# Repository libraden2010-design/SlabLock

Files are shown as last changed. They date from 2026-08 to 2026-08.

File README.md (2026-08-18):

# SlabLock

A 3D-printed display case for PSA-graded card slabs, designed in OpenSCAD and printed on a Bambu X2D (PLA).

## Features

- Slide-lock lid with 45-degree dovetail rails (no flex parts, nothing breaks)
- Side magnets (8x2mm N52) for case-to-case linking
- Flat stacking with chamfered rim keying
- Single-piece lid (V5) with retaining groove for clear plastic sheet
- Push-out hole for easy slab removal

## Files

- `POLYGENCE_SLIDE_LOCK.scad` — parametric OpenSCAD source (single file, all parts)
- `BUILD_LOG.md` — design iteration history, mistakes, and lessons learned
- `stl/` — exported STL files by version

## Printing

- **Printer**: Bambu X2D (or any FDM)
- **Material**: PLA
- **Export**: Set `export_part` in the SCAD file — `"frame"` or `"lid"`
- **Orientation**: Frame prints back-face down, lid prints mating-face down
- **No supports needed**

## Clear Sheet

Cut a clear plastic sheet (PET or acetate) to the dimensions shown in the OpenSCAD console output. The sheet slides into the lid's C-channel grooves from the top edge.

## Magnets

8x2mm N52 neodymium discs, 3 per side. Use CA glue or 5-minute epoxy (not Gorilla Glue). Mark polarity with Sharpie before installing.

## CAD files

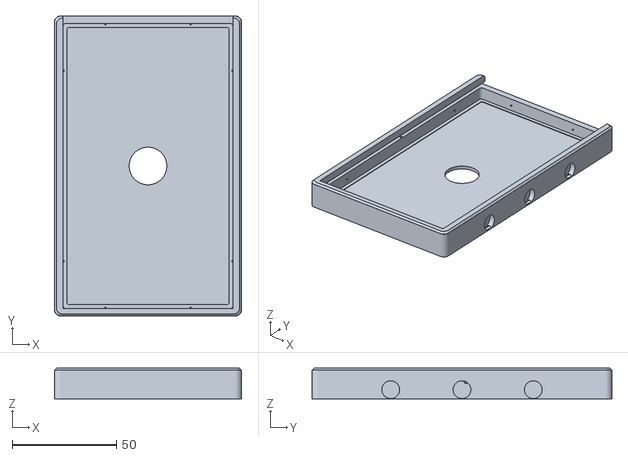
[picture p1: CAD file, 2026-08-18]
stl/v5/Frame.stl
89.6 x 143.6 x 14.7

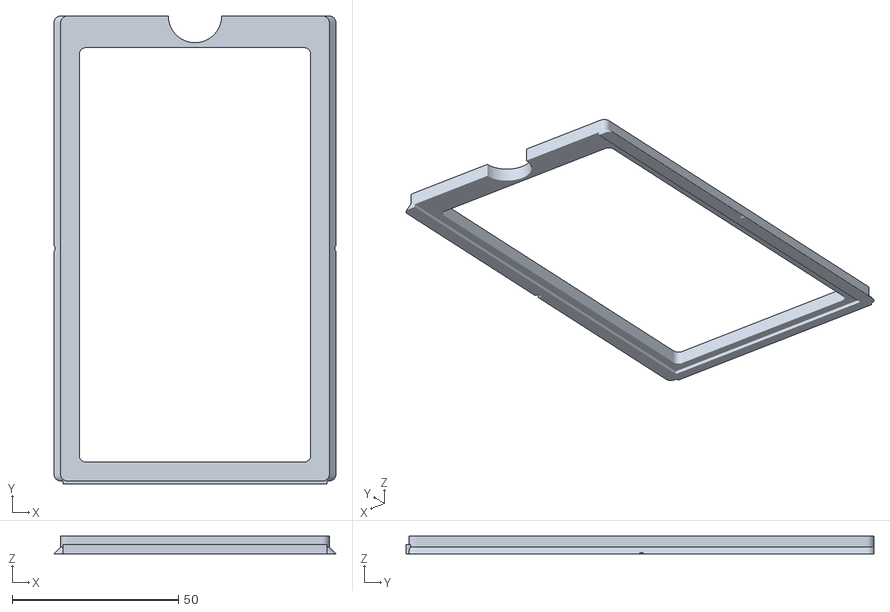
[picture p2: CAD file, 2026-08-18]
stl/v5/Lid-Single-Piece.stl
84.8 x 140.7 x 5.30

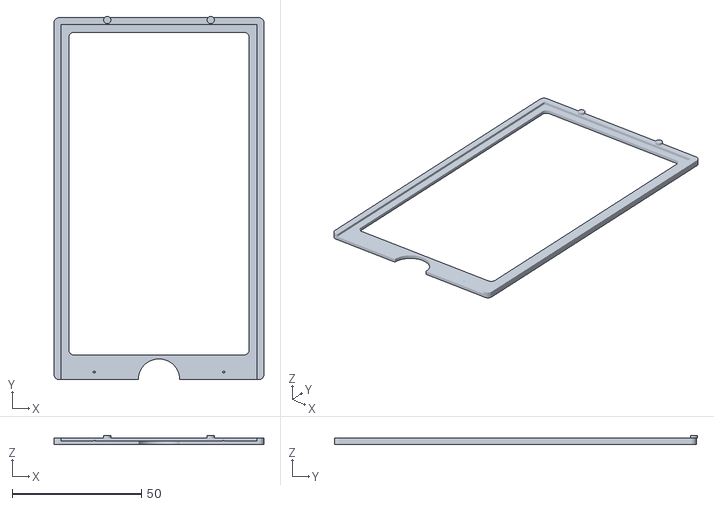
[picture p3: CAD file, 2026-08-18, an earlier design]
stl/v4/Lid-Front-V4.stl
81.1 x 140.3 x 3.50

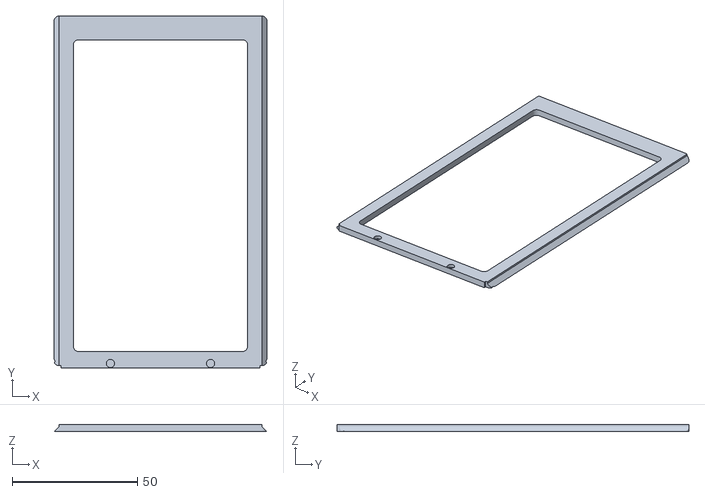
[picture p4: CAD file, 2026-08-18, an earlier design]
stl/v4/Lid-Back-V4.stl
85.1 x 140.7 x 2.80

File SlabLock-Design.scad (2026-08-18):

// ============================================================
// PSA Slab Display — V5: SINGLE-PIECE LID
// ============================================================
// The lid SLIDES into the frame from the top edge, like a
// battery cover:
//   - Frame side walls extend up into dovetail RAILS that wrap
//     over the lid's chamfered edges (captures it vertically)
//   - A raised STOP WALL at the bottom edge ends the travel
//   - A tiny detent bump clicks into a divot in the lid at the
//     seated position
// NOTHING flexes more than a few hundredths of a mm -> nothing
// breaks, in any material.
//
// The lid is ONE PIECE (5.3mm) with a rabbet (shallow recess)
// on the mating face for the clear sheet. No sandwich, no pins,
// no second plate.
//
// PRINT (all flat, no supports):
//   "frame" - rails print with 45-degree self-supporting undersides
//   "lid"   - prints mating-face-DOWN (chamfers slope inward = safe)
//
// CLEAR SHEET: see echo() output for dimensions.
// ============================================================

// ---- EXPORT MODE ----
// "frame" | "lid" | "assembled"
export_part = "assembled";

// ---- Slab + fit ----
slab_w = 81;  slab_h = 136;  slab_t = 6.5;
fit = 0.3;  mag_tol = 0.15;

// ---- Walls ---- (original proportions — the slim pass was reverted)
back_t = 2.0;  wall_t = 4.0;  bot_t = 3.5;  top_t = 3.5;  corner_r = 3;

// ---- Slab pocket rim ----
rim_w = 2.0;  rim_extra = 0.3;

// ---- Side magnets (case-to-case linking; flush mount) ----
// 6x2 (not 6x3): a 2mm-deep seat can sit CENTERED on the tall wall
// without breaking into the dovetail channel behind it.
// Bore is 0.4 oversize so printed-hole shrinkage can't block the
// magnet — the crush ribs (sized off mag_d, not the bore) do the
// actual gripping.
// 8x2: biggest disc that sits CENTERED on the wall — the thin 2mm
// profile keeps the seat shallow enough to clear the lid channel.
mag_d = 8;  mag_t = 2;  mags_per_side = 3;
mag_hole_d = mag_d + 0.5;
mag_seat_depth = mag_t + 1.0;   // 3mm bore — magnet at back, 1mm gap for superglue plug

// ---- Closure magnets (lid <-> frame, optional helpers now) ----
cmag_d = 5;  cmag_t = 2;  cmag_tol = 0.2;
cmag_hole_d = cmag_d + cmag_tol;

// ---- Lid (single piece with rabbet for clear sheet) ----
lid_border = 6;
sheet_t       = 0.8;
sheet_clear   = 0.25;
back_plate_t  = 2.8;         // tuck tongue height (matches frame groove)
lid_t         = 5.3;         // total thickness — matches frame channel
rabbet_depth  = 1.0;         // shallow recess for sheet (frame traps it)
capture       = 3.0;         // sheet overlap past window edge
thumb_notch_r = 8;

// ---- [V4] Slide-lock geometry ----
rail_w    = 2.0;    // rail footprint on top of each side wall
rail_h    = 2.0;    // dovetail height (45-degree faces)
slide_clr = 0.40;   // sliding clearance per side (0.25 was too tight for FDM)
// Full-height channel: the whole lid nests inside the frame rim, which
// stands 0.6 proud of the lid face — that proud rim doubles as the
// stacking key (nests into the back recess of the case above)
rim_proud = 0.6;
chan_h    = lid_t + rim_proud;       // channel height above frame face
stop_clr  = 0.3;    // lid-to-stop-wall end clearance

// [STACK] GradedGuard-style flat stacking: a recessed CHANNEL ring in
// the back receives the chamfered rim crest of the case below.
// A 0.7 skirt at the outer edge keeps the border anchored to the bed
// (the v1 full-ring recess left the whole border starting mid-air —
// unprintable, caused repeated print failures).
stack_recess_depth = rim_proud + 0.15;
stack_skirt = 0.7;     // outer edge strip that still touches the bed
rim_cham    = 1.0;     // 45-degree chamfer on the rim crest (entry guide)

// [TUCK] Undercut pocket in the stop wall: a tongue on the lid's
// bottom edge slides in, fully capturing the bottom edge
tuck_depth = 0.9;            // how far the tongue enters the wall
tuck_groove = tuck_depth + 0.3;
tuck_hw = 39.7;              // tongue half-width (groove is 40)

// Detent (click at seated position)
det_bump_r = 0.9;   det_bump_protrude = 0.3;
det_divot_r = 1.5;  det_divot_depth = 0.4;


// ---- Derived ----
pocket_w = slab_w + 2*fit;
pocket_h = slab_h + 2*fit;
inner_w  = slab_w - 2*rim_w + 2*fit;
inner_h  = slab_h - 2*rim_w + 2*fit;
outer_w  = pocket_w + 2*wall_t;
outer_h  = pocket_h + top_t + bot_t;
frame_d  = back_t + slab_t + fit;
open_w   = slab_w - 2*lid_border + 2*fit;
open_h   = slab_h - 2*lid_border + 2*fit;
yoff     = (top_t - bot_t) / 2;

// [V4] channel / lid outline
chan_base_hw = outer_w/2 - rail_w;        // 42.8 channel floor half-width
chan_top_hw  = chan_base_hw - rail_h;     // 40.8 between rail tips
lidb_base_hw = chan_base_hw - slide_clr;  // 42.55 back plate at mating face
lidb_top_hw  = lidb_base_hw - rail_h;     // 40.55 back plate above chamfer
stop_y   = -(outer_h/2) + bot_t + yoff;   // inner face of bottom stop wall
lid_y0   = stop_y + stop_clr;             // lid bottom edge
lid_y1   = outer_h/2 + yoff;              // lid top edge (flush w/ frame)
lid_len  = lid_y1 - lid_y0;
lid_yc   = (lid_y0 + lid_y1) / 2;

// Sheet groove area (C-channel behind retaining lip)
rabbet_w   = open_w + 2*capture;
rabbet_bot = yoff - open_h/2 - capture;
rabbet_top = lid_y1 + 1;

sheet_w = rabbet_w - 2*sheet_clear;
sheet_h = lid_y1 - rabbet_bot - 1;

// Detent positions
det_y  = lid_yc;                          // centered vertically on the lid
det_x  = (pocket_w/2 + chan_base_hw)/2;   // centered on the side ledges (41.7)

// Side magnet height: centered in the frame body (not the channel area)
// so the full 4mm wall is behind the seat — no breakthrough into the
// dovetail channel. Magnets stay fully captured.
smag_z = frame_d / 2;

// [V5] Stacking magnet x positions (must sit in the solid part of the
// top edge band, i.e. below frame_d — any x inside the walls works)
stackmag_x = 30;

// Push-out hole in the back floor (centered on the slab)
push_hole_d = 18;


// Closure magnet corner positions (unchanged)
cmag_inset = 6 + cmag_d/2;
cmag_xy = [
    [-(outer_w/2) + cmag_inset, -(outer_h/2) + cmag_inset + yoff],
    [ (outer_w/2) - cmag_inset, -(outer_h/2) + cmag_inset + yoff],
    [-(outer_w/2) + cmag_inset,  (outer_h/2) - cmag_inset + yoff],
    [ (outer_w/2) - cmag_inset,  (outer_h/2) - cmag_inset + yoff]
];

$fn = 96;
module rrect(w,h,r) { offset(r) offset(-r) square([w,h], center=true); }


echo(str("=== CUT CLEAR SHEET TO: ", sheet_w, " x ", sheet_h,
         " mm, thickness <= ", sheet_t, " mm ==="));


// ============================================================
// FRAME with slide rails + bottom stop
// ============================================================
module frame() {
    difference() {
        // Full outline up to rail top; the channel cut leaves
        // rails on the sides, a stop wall at the bottom, and an
        // open insertion mouth at the top edge.
        linear_extrude(frame_d + chan_h)
            rrect(outer_w, outer_h, corner_r);

        // [V4] Lid slide channel — dovetail profile, open at top edge
        translate([0, lid_y1 + 5, 0])
            rotate([90, 0, 0])
                linear_extrude(lid_y1 + 5 - stop_y)
                    polygon([
                        [-chan_base_hw, frame_d],
                        [ chan_base_hw, frame_d],
                        [ chan_top_hw,  frame_d + rail_h],
                        [ chan_top_hw,  frame_d + chan_h + 5],
                        [-chan_top_hw,  frame_d + chan_h + 5],
                        [-chan_top_hw,  frame_d + rail_h]
                    ]);

        // Outer slab pocket
        translate([0, yoff, back_t])
            linear_extrude(slab_t + fit + 0.1)
                rrect(pocket_w, pocket_h, 1.5);

        // Inner pocket (stepped ledge)
        translate([0, yoff, back_t - rim_extra])
            linear_extrude(slab_t + fit + rim_extra + 0.1)
                rrect(inner_w, inner_h, 1);

        // Side magnets L — 3mm bore from outside. Push magnet to the back
        // with a stick, then fill the remaining 1mm with superglue. The
        // glue bonds to the PLA bore walls (strong) and blocks the magnet.
        for (i = [0:mags_per_side-1]) {
            yp = (i+1)*pocket_h/(mags_per_side+1) - pocket_h/2 + yoff;
            translate([-(outer_w/2) - 0.01, yp, smag_z])
                rotate([0, 90, 0])
                    cylinder(d = mag_hole_d, h = mag_seat_depth + 0.01);
        }
        // Side magnets R
        for (i = [0:mags_per_side-1]) {
            yp = (i+1)*pocket_h/(mags_per_side+1) - pocket_h/2 + yoff;
            translate([(outer_w/2) + 0.01, yp, smag_z])
                rotate([0, -90, 0])
                    cylinder(d = mag_hole_d, h = mag_seat_depth + 0.01);
        }
        // (Top/bottom edge stacking-magnet holes removed per final design.)
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

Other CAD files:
stl/v4/Frame-V4.stl

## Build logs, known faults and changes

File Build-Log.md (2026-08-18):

# SlabLock Build Log

PSA slab display case — designed in OpenSCAD, printed on Bambu X2D (PLA).

---

## V1 — Initial Frame + Two-Piece Lid

**Goal**: A slim frame that holds a PSA-graded card slab, with a slide-on lid and side magnets for case-to-case linking.

**Design decisions**:
- Frame with recessed slab pocket (81 x 136 x 6.5mm slab, 0.3mm fit tolerance)
- Slide-lock lid in two pieces (back plate + front plate) that sandwiches a clear plastic sheet
- Side magnets: 3 per side, Total Element 8x2mm N52 neodymium
- Closure magnets in corners for lid retention
- Push-out hole in back face so you can pop the slab out with your thumb

**What worked**:
- Frame printed cleanly on first try
- Slide-lock mechanism engages and holds
- Slab fits in the pocket with good tolerance

**What didn't work**:
- Magnet bores punched through into the lid channel wall (only ~2mm thick at that Z height)
- Glue leaked into the lid channel through the bore-through
- N52 magnets pulled each other out of their bores despite superglue — the glue bond on the smooth magnet surface was too weak

---

## V2 — Magnet Position Fix

**Problem**: Magnet bores at the original Z height (near the lid channel) bored through only 2mm of wall.

**Fix**: Moved `smag_z` from channel area to `frame_d / 2` — centers the bore in the full 4mm wall body. No more bore-through.

**Result**: Bores no longer leak into the channel. But magnets still pulled out.

---

## V3 — "Stepped Bore" Attempt (Failed)

**Problem**: Magnets still get yanked out by adjacent magnets.

**Attempted fix**: Designed a "stepped bore" — wide 8.5mm chamber inside with a narrow 6.5mm mouth at the entrance. Idea was that the magnet presses past the step during assembly and is physically trapped.

**What actually happened**: The OpenSCAD code was buggy. Both cylinder cuts used the same diameter (`mag_hole_d = 8.5mm`), so there was literally no step. Just a straight 2.8mm hole. The "retention mechanism" never existed.

**Lesson**: Always verify generated geometry in the preview — don't assume the code does what the comments say.

---

## V4 — Deep Bore + Glue Plug (Current)

**Problem**: Need actual magnet retention that works.

**Fix**: Simple 3mm deep bore (was 2.2mm). The magnet (2mm thick) gets pushed to the back of the bore, leaving 1mm of empty space at the entrance. Fill that gap with adhesive.

**Why this works**: The adhesive bonds to the PLA bore walls all around (PLA-to-adhesive = strong bond), not to the magnet's smooth surface (weak bond). The cured plug physically blocks the magnet from exiting.

**Adhesive findings**:
- Gorilla Glue (polyurethane): BAD — expands and foams, leaves white residue around the bore entrance
- Superglue (CA): Better — cures clear, no foam, but works best in thin layers
- 5-minute epoxy: Best — fills gaps well, cures rigid, strong PLA bond

**Polarity tip**: Stack all magnets, mark the same face with Sharpie before installing. All marked faces point the same direction so cases attract.

---

## Kickstand — Attempted and Abandoned

Tried 6+ designs for a fold-flat kickstand recessed into the back face:

1. **Clip-on bar** — rejected
2. **Hinge pin** — too tight, wouldn't rotate
3. **Snap-in posts** — couldn't snap into place
4. **Slide-out strip** — extended below frame edge, ugly
5. **Built-in shelf** — terrible
6. **Drop-in U-cradle with nubs** — nubs were too small (1.6mm plate), retaining bumps (0.3mm spheres) did nothing. Kickstand looked "just floating" with no convincing mechanical connection
7. **Pivot pins with slots** — 1.2mm pins on frame walls, matching slots in kickstand. Geometrically sound but plate too thin (1.6mm) for reliable pin engagement

**Core constraint**: The back wall is only 2mm thick (`back_t`), and the kickstand pocket overlaps with the slab pocket in Z, limiting pocket depth. A 1.6mm plate is too thin for any robust pivot mechanism (pin holes, snap fits, etc.).

**Decision**: Removed the kickstand entirely. A separate stand or easel is simpler and more reliable.

**Lesson**: Don't force a mechanism into geometry that can't support it. The 2mm back wall was never enough for a integrated hinge.

---

## Lid — V4 Two-Piece (Replaced)

The V4 lid was two printed plates that sandwiched a hand-cut clear plastic sheet:
- `lid_back`: sat on the frame's front face, had the slide-lock tongue
- `lid_front`: clipped over lid_back, trapped the clear sheet between them

**Problems**:
- Two separate parts + a cut sheet = 3 components for one lid
- Assembly was fiddly (alignment pins, gluing two plates together)
- Overkill for just holding a clear window

---

## Lid — V5 Single Piece (Current)

**Problem**: Two-piece lid was unnecessarily complex.

**Fix**: Merged `lid_back` and `lid_front` into a single `lid()` module. Same 5.3mm total thickness so it fits the existing frame channel without reprinting.

**Design**:
- Same dovetail-chamfered XZ profile as old `lid_back` (wide base 42.55mm, narrow top 40.55mm)
- Rabbet (shallow recess, ~1.05mm deep) on the mating face holds the clear sheet
- Through-cut viewing window
- Tuck tongue at bottom edge (same as before)
- Detent divots (same as before)
- Thumb notch at top edge for gripping
- No pins, no second plate, no glue sandwich

**Removed**: `lid_front` module, alignment pins (`pin_d`, `pin_h`, `pin_xy`), `slot_gap`, `front_plate_t`, `front_web_t`, `lidf_hw`. Old `slot_w`/`slot_y_bot` renamed to `rabbet_w`/`rabbet_bot`.

**Export**: `export_part="lid"` (replaces "lid_back", "lid_front", "lid_both")

**Status**: STLs exported (V5_frame.stl, V5_lid.stl). Frame unchanged — only the lid was redesigned.

---

## Printing Notes

- **Printer**: Bambu X2D
- **Material**: PLA
- **Orientation**: Frame prints back-face down. Lid prints mating-face down.
- **FDM hole shrinkage**: Printed holes come out 0.2-0.5mm smaller than designed. The 8.5mm magnet bore (`mag_d + 0.5`) accounts for this.
- **Clear sheet**: Cut to 75.1 x 136.1mm, thickness 0.8mm or less. X-Acto knife.

---

## Open Items

- [x] Redesign lid as single piece with rabbet for clear sheet (V5)
- [ ] Print V5 lid and test fit
- [ ] Test epoxy vs CA glue for magnet retention long-term
- [ ] Evaluate whether a separate stand/easel is needed
- [ ] Cut clear plastic sheet to size (75.1 x 136.1mm, <=0.8mm thick)

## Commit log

2026-08-18 Initial commit: SlabLock PSA slab display case
    OpenSCAD parametric design with slide-lock lid, side magnets,
    flat stacking, and single-piece lid with sheet retention grooves.
    Includes V4 and V5 STLs and full build log.
    [POLYGENCE_SLIDE_LOCK.scad, V4_frame.stl, V4_lid_back.stl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]
2026-08-18 Rename files with clear descriptive names
    [Frame-V4.stl, Frame.stl, Lid-Back-V4.stl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]
2026-08-18 Center detent bumps on the lid, increase mesh resolution
    Moved detent from the bottom band to the vertical center of the
    lid — eliminates the large empty gap. Bumped $fn from 64 to 96
    and replaced intersection() with hull() for smoother lid geometry.
    [Frame.stl, Lid-Single-Piece.stl, SlabLock-Design.scad]
2026-08-18 Simplify lid: remove groove/lip, widen slide clearance
    - Replaced C-channel grooves + retaining lip with a simple flat
    rabbet. The frame traps the sheet when the lid is installed.
    - Increased slide_clr from 0.25 to 0.40mm to fix inconsistent
    friction from FDM tolerances.
    - Assembly is now: place sheet on lid, slide into frame, done.
    [Frame.stl, Lid-Single-Piece.stl, SlabLock-Design.scad]
